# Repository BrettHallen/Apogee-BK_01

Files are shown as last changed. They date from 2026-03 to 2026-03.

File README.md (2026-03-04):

# Апогей БК 01/Apogee BK 01
Information about the Soviet Apogee BK 01 computer, an implementation of the Радио 86РК/Radio 86RK design.

## [New Power Supply](/Apogee-BK_01_Power)
As the Apogee uses the 8080 it requries a tri-voltage power supply, ±5VDC and +12VDC, via a 7-pin DIN.  This is my simple implementation of a replacement using a single +12VDC power source, generating the ±5V via two switching regulators.<br>

- Pin 1 = +5V regulated
- Pin 2 = +5V regulated
- Pin 3 = +12V regulated
- Pin 4 = -5V unregulated
- Pin 5 = ground (общий)
- Pin 6 = ground (общий)
- Pin 7 = fault (авария)

The fault/авария signal on the motherboard monitors the +5V rail relative to the -5V rail.  If the +5V rail drifts too far out of range (over/undervoltage) then it will signal the power supply to shut off the linear regulators (КР142ЕН1Б, similar to Western UA723).

## [Schematics](/Schematics)
High quality scans of the original schematics.

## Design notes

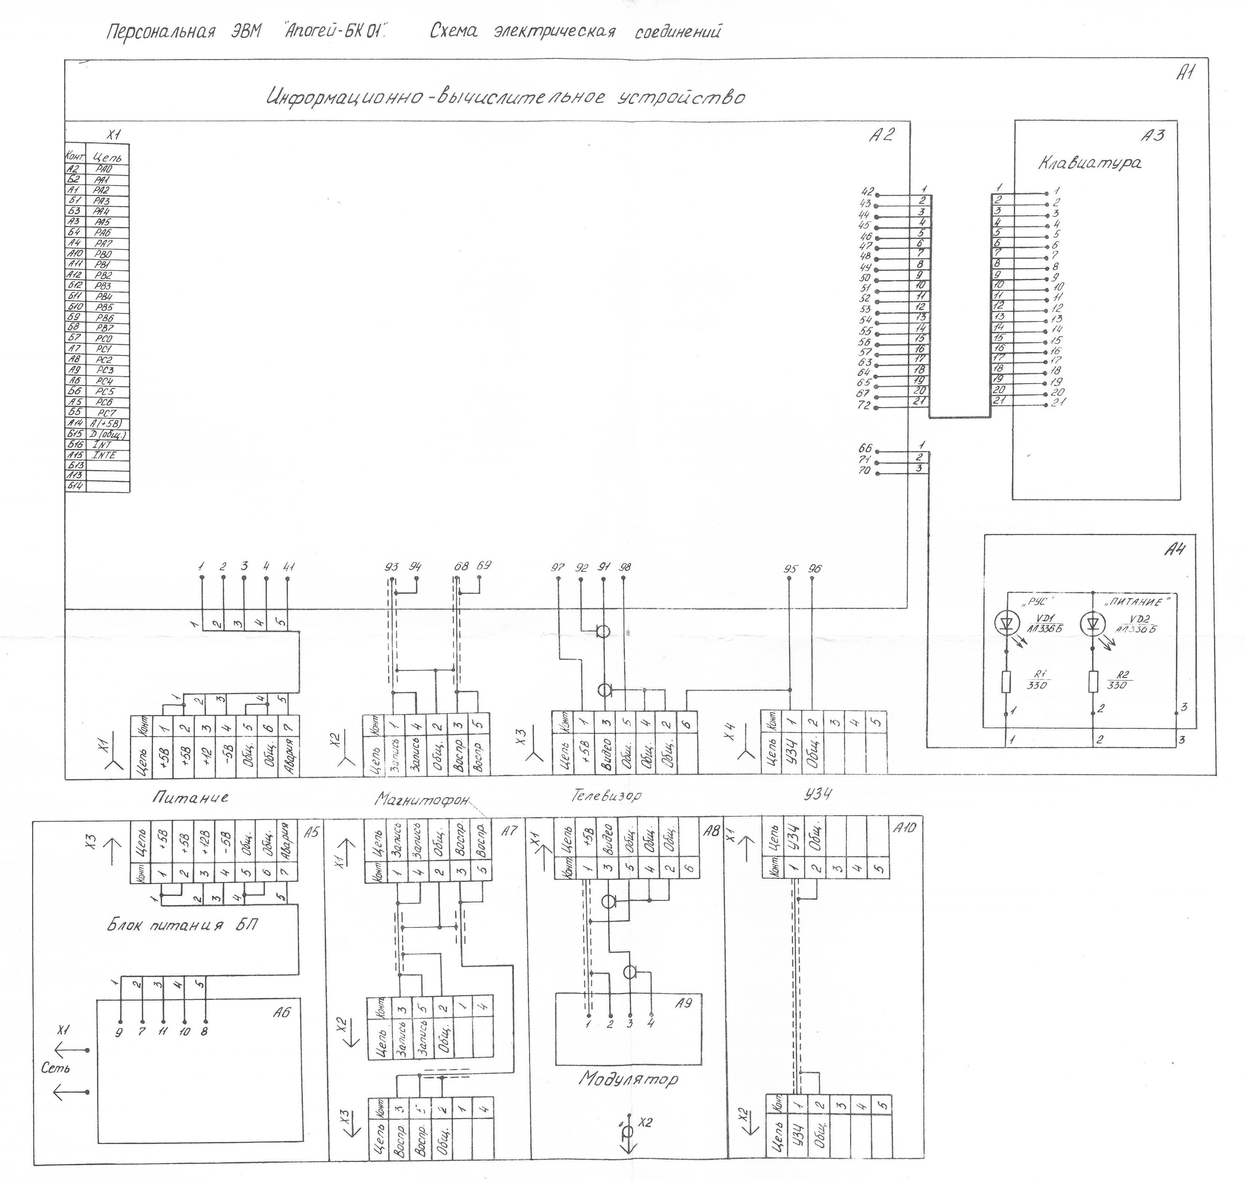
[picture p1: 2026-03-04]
Schematics/Apogee_BK01_Schematic6.jpg

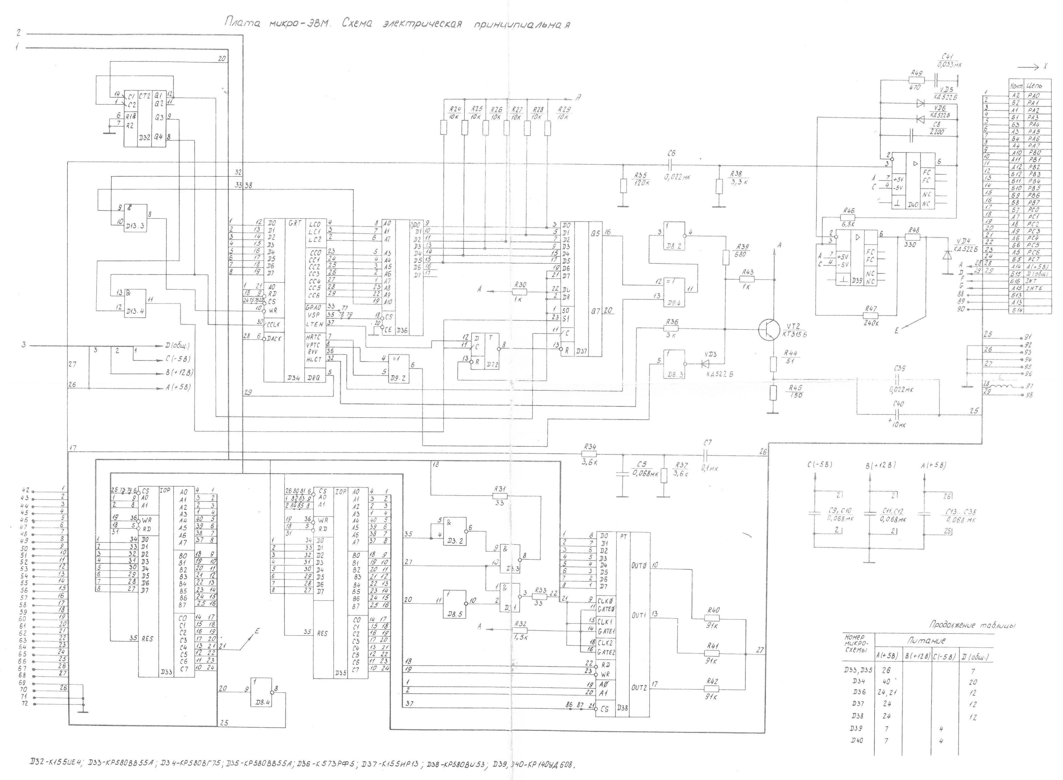
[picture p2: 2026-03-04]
Schematics/Apogee_BK01_Schematic3.jpg

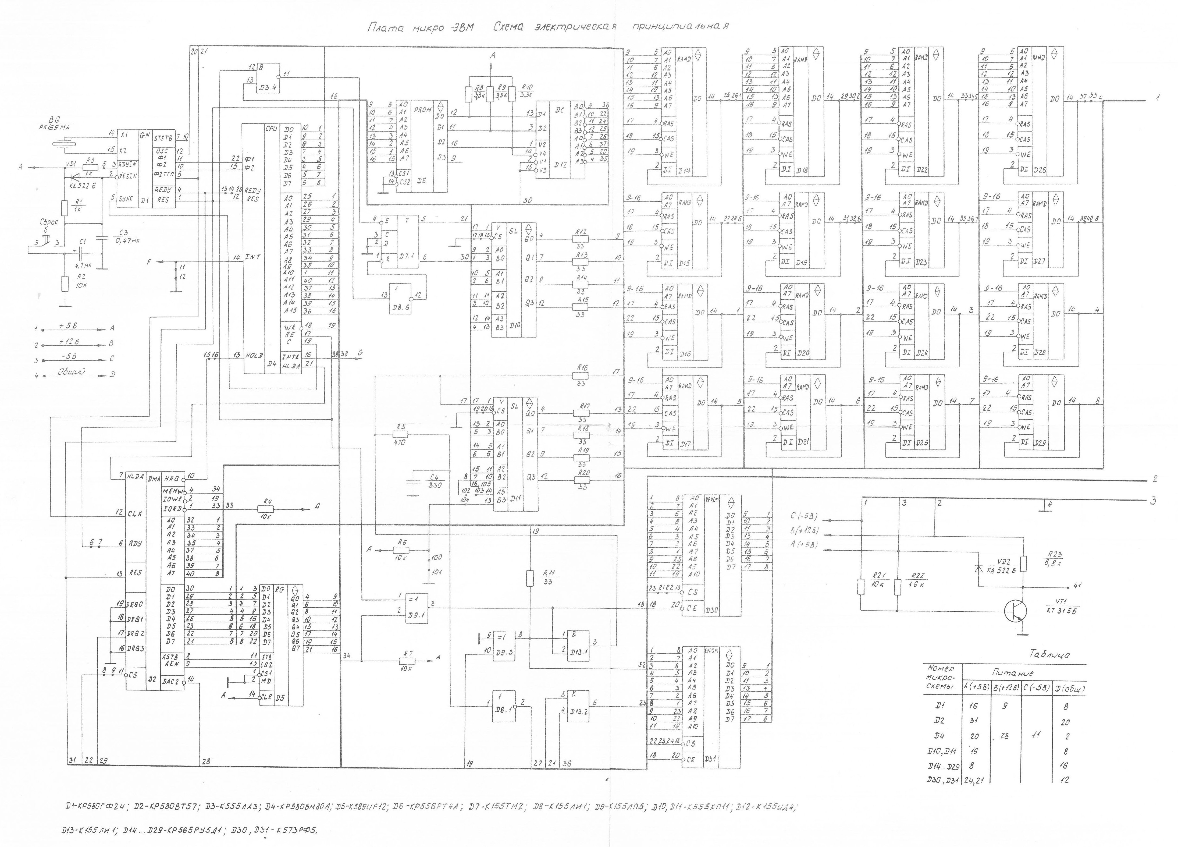
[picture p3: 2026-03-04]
Schematics/Apogee_BK01_Schematic2.jpg

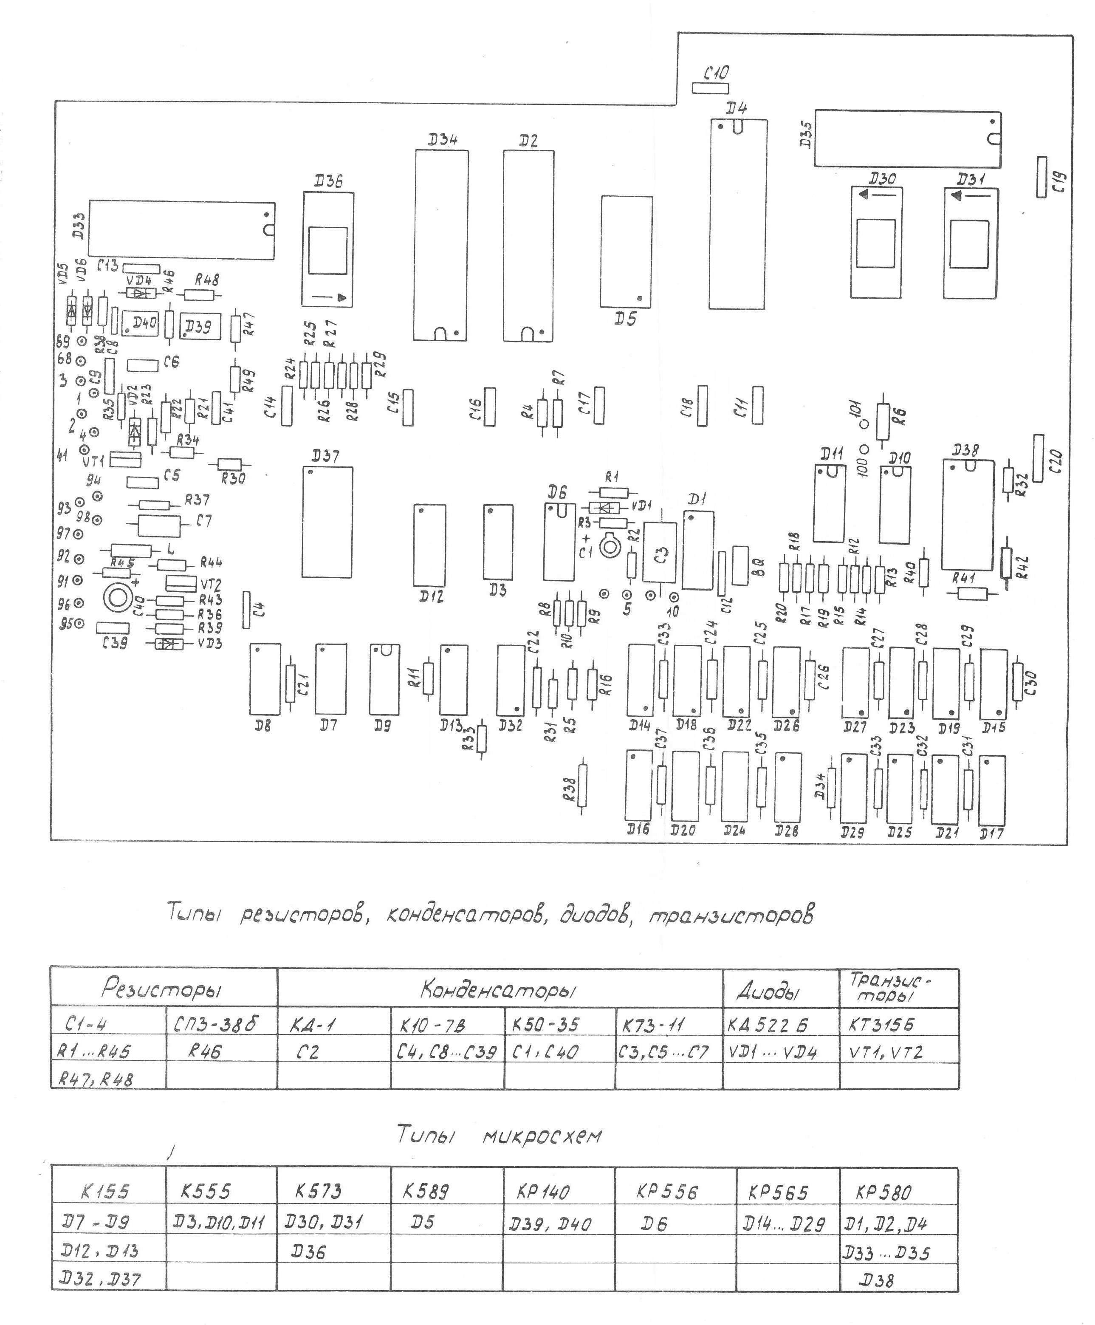
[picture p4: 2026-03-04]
Schematics/Apogee_BK01_Schematic1.jpg

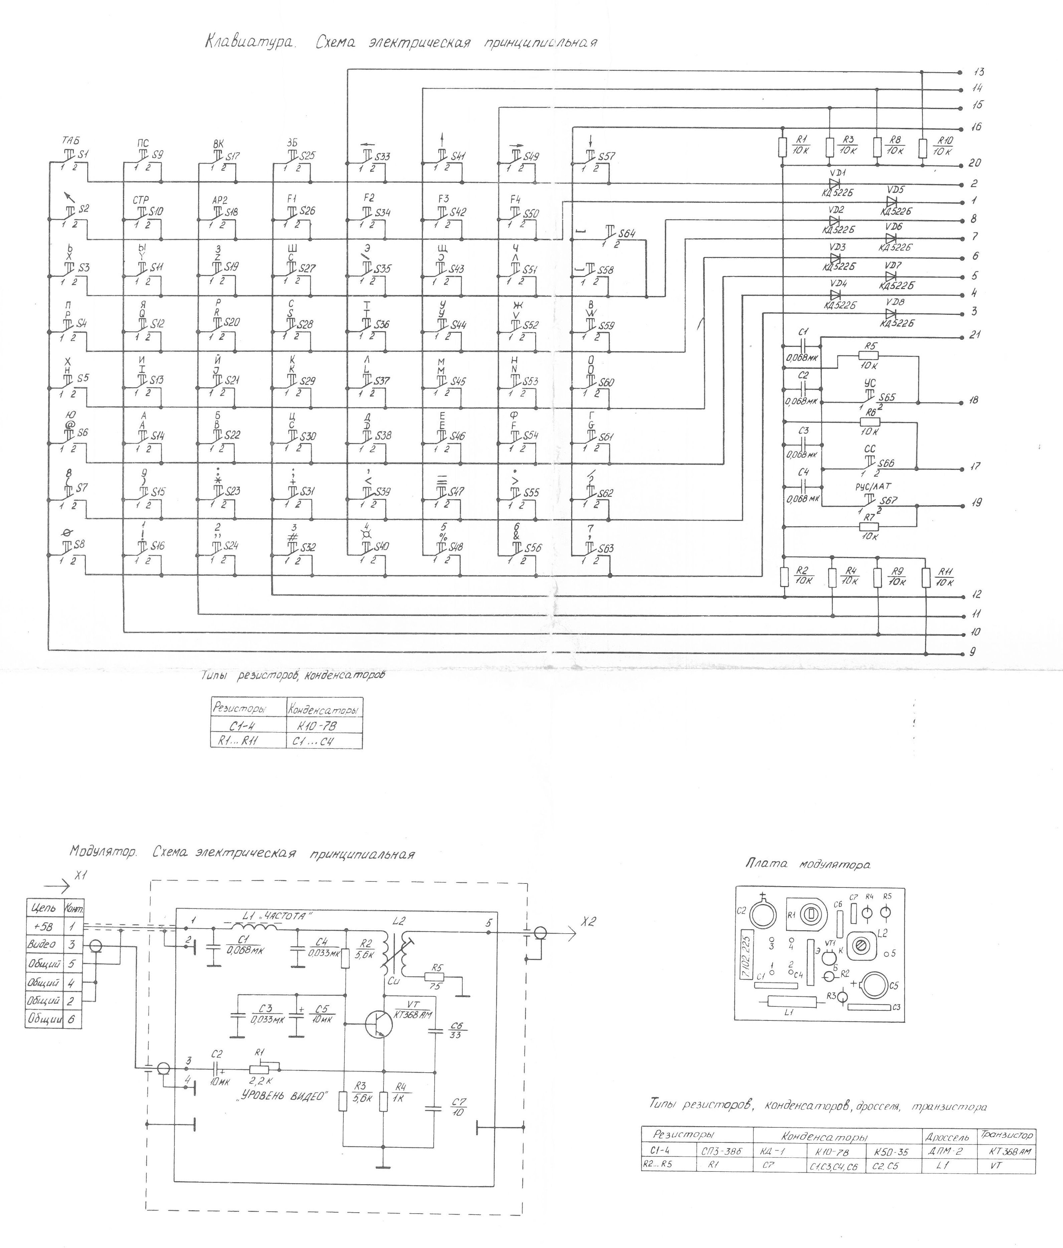
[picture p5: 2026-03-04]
Schematics/Apogee_BK01_Schematic7.jpg

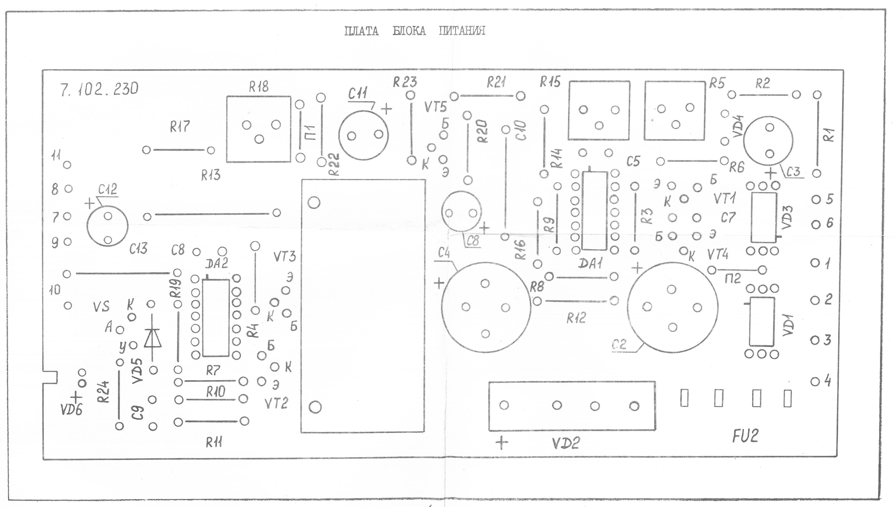
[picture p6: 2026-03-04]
Schematics/Apogee_BK01_Schematic5.jpg

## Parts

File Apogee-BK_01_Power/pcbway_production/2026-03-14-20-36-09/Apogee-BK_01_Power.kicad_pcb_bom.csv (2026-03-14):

Designator | Quantity | Value | Footprint | Package | MPN | DNP | Mount_Type | Description | Height | Manufacturer_Name
C1, C2 | 2 | 100µF | CP_Radial_D6.3mm_P2.50mm |  |  |  | tht | Polarized capacitor
C3, C4 | 2 | 100nF | C_Disc_D3.8mm_W2.6mm_P2.50mm |  |  |  | tht | Unpolarized capacitor
F1 | 1 | Fuse | Fuseholder_Clip-5x20mm_Littelfuse_111_Inline_P20.00x5.00mm_D1.05mm_Horizontal |  |  |  | tht | Fuse
J1 | 1 | Power In (+12VDC) | BarrelJack_CUI_PJ-063AH_Horizontal |  |  |  | tht | DC Barrel Jack
J2 | 1 | Power Out | 6710801 |  |  |  | tht | Generic connector, single row, 01x07, script generated (kicad-library-utils/schlib/autogen/connector/)
U1 | 1 | PSU5 | TO-3 |  |  |  | tht
U2 | 1 | R-78CK5.0-0.5 | TO-220-3_Vertical |  | R-78CK5.0-0.5 |  | tht | 0.5A DC/DC-Converter \'INNOLINE\' SIP3 reg | 10.7 | RECOM Power

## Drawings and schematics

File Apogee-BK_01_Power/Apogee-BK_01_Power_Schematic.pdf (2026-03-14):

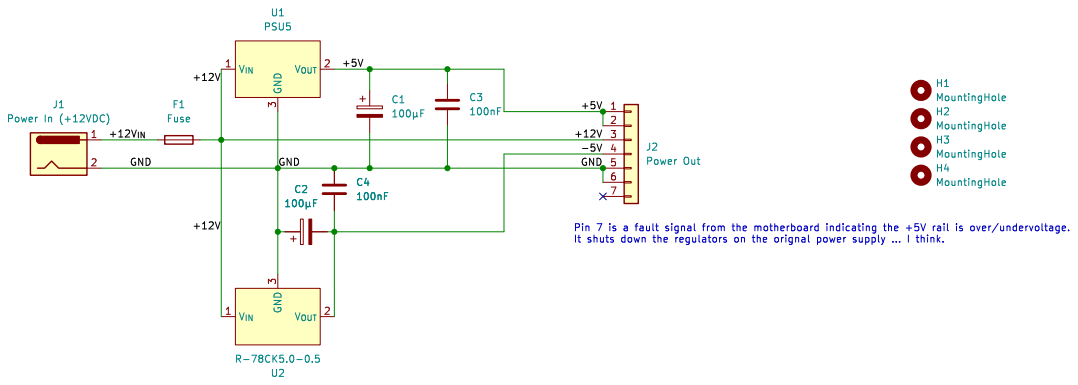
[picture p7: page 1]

Id: 1/1 Title: þÿ?>359 Power Supply

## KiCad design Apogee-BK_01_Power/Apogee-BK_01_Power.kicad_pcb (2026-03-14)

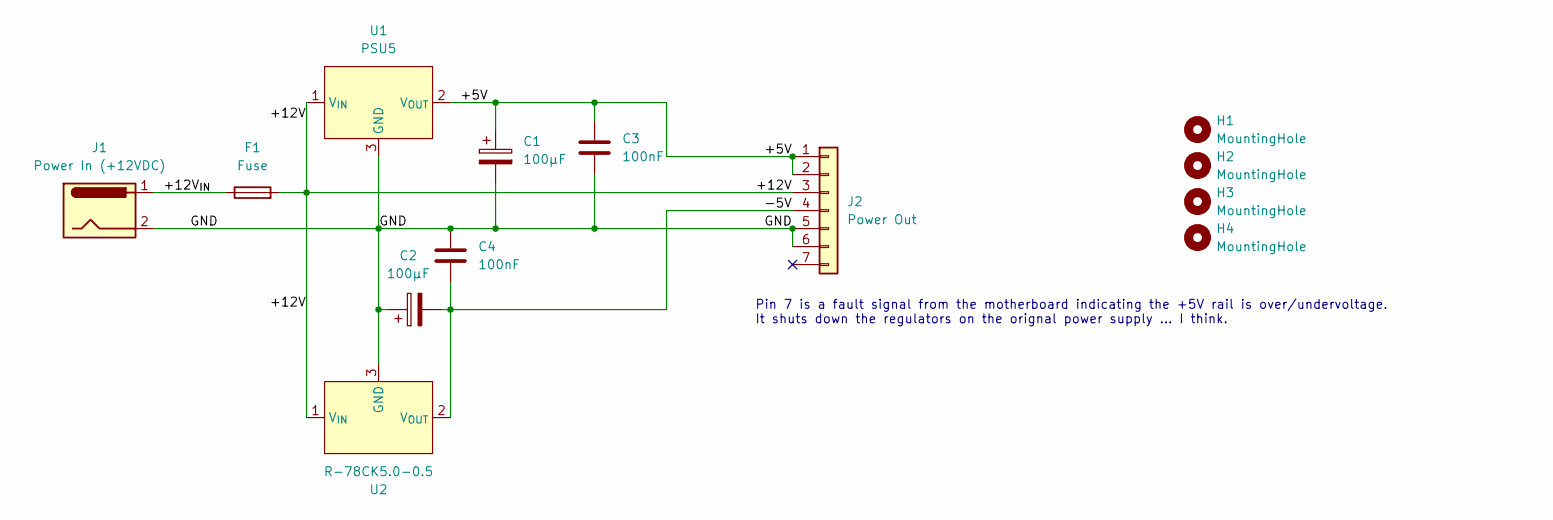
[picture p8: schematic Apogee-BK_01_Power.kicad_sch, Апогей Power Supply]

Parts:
C1, C2: 100µF; CP_Radial_D6.3mm_P2.50mm
C3, C4: 100nF; C_Disc_D3.8mm_W2.6mm_P2.50mm
F1: Fuse; Fuseholder_Clip-5x20mm_Littelfuse_111_Inline_P20.00x5.00mm_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
H1, H2, H3, H4: MountingHole; MountingHole_3.2mm_M3_DIN965
J1: Power In (+12VDC); BarrelJack_CUI_PJ-063AH_Horizontal
J2: Power Out; 6710801
U1: PSU5; TO-3
U2: R-78CK5.0-0.5; TO-220-3_Vertical; Manufacturer_Part_Number R-78CK5.0-0.5

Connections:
/+5V: C1.1, C3.1, J2.1, J2.2, U1.2 (V_{OUT})
/+12V: F1.2, J2.3, U1.1 (V_{IN}), U2.1 (V_{IN})
/+12V_{IN}: F1.1, J1.1
/-5V: C2.2, C4.1, J2.4, U2.2 (V_{OUT})
/GND: C1.2, C2.1, C3.2, C4.2, J1.2, J2.5, J2.6, U1.3 (GND), U2.3 (GND)

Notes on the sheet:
Pin 7 is a fault signal from the motherboard indicating the +5V rail is over/undervoltage. It shuts down the regulators on the orignal power supply ... I think.

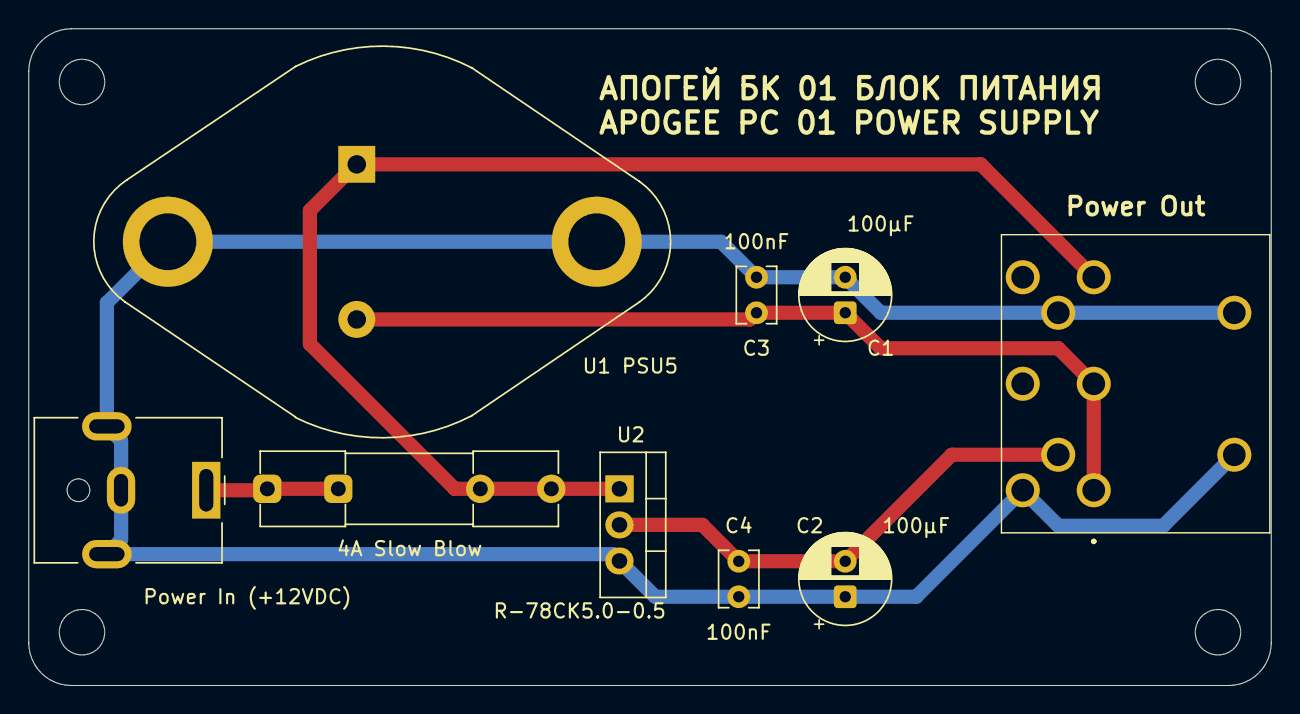
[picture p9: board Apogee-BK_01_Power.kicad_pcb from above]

Board: 2 copper layers, 87.5 x 46.2 mm, 13 parts (0 on the bottom side), 5 nets.

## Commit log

2026-03-04 Scans of schematics
2026-03-14 Added fuse to 12V input rail
    [Apogee-BK_01_Power.kicad_pcb, Apogee-BK_01_Power.kicad_pcb_bom.csv, Apogee-BK_01_Power.kicad_pcb_positions.csv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]
